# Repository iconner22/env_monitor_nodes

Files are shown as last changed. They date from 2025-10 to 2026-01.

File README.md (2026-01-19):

## Project Overview
This project implements **multihop, ad-hoc wireless sensor network (WSN)** for environmental monitoring. The system is built around Arduino UNO nodes that communicate using a 915 MHz transciever and a centeral gateway that handles requests and data storage. The gateway node requests temperature and humidity at sent intervals and collects sound data based on a monitored threshold. The network performs a discovery upon initialization which allows for ad-hoc distribution and supports multi-hop communication based on a path supplied by the gateway.

## Hardware
The system is built off of Arduino UNOs and custom PCB shields which integrate the RF transciever and sensors into the microcontroller.

<figure>
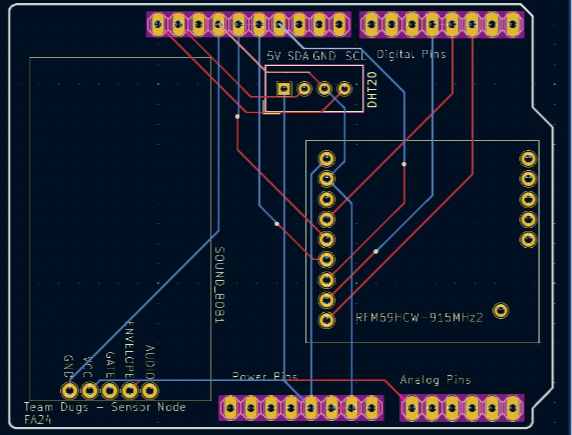
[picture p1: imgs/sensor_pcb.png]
Custom PCB for Sensor Nodes
  
  <figcaption>Custom PCB for Sensor Nodes.</figcaption>
</figure>

<figure>
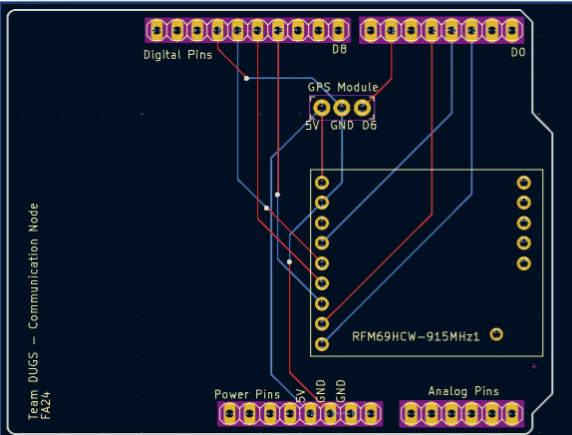
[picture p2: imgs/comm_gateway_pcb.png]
Custom PCB for Communication and Gateway Nodes
  
  <figcaption>Custom PCB for Communication and Gateway Nodes.</figcaption>
</figure>

## Node Types

The network is composed of three distinct node roles: **sensor nodes**, **communication nodes**, and a **gateway node**. All nodes share a common hardware and software base, with behavior determined by role-specific logic and sensors.

### Sensor Nodes
<figure>
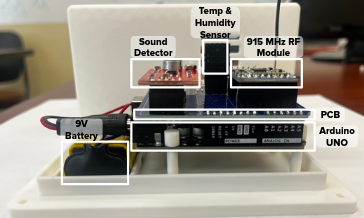
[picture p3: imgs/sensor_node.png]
Sensor Node
  
  <figcaption>Assembled Sensor Node.</figcaption>
</figure>
Sensor nodes are responsible for collecting and reporting environmental data. These nodes interface with temperature, humidity, and sound sensors.

Sensor nodes:
- Respond to gateway-initiated requests for environmental or GPS data
- Participate in network discovery and routing
- Transmit sound data upon trigger
- Prioritize low-power operation during idle periods

### Communication Nodes
<figure>
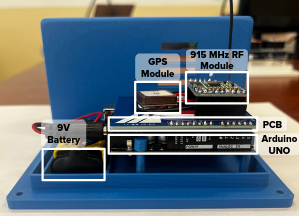
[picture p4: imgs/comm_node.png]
Communication Node
  
  <figcaption>Assembled Communication Node.</figcaption>
</figure>
Communication nodes help in the routing and localization of the network.

Communication nodes:
- Participate fully in discovery and routing
- Forward packets between sensor nodes and the gateway
- Maintain routing state during the discovery phase
- Improve network robustness and multihop coverage
- Record GPS coordinates used in trilateration

### Gateway Node
<figure>
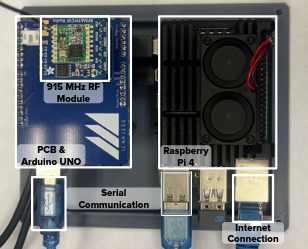
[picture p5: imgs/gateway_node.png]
Gateway Node
  
  <figcaption>Assembled Gateway Node.</figcaption>
</figure>
The gateway node serves as the **root of the network** and the primary interface between the WSN and external systems. The Arduino UNO is connected to a RasperryPi which handles the routing protocols and publishing of data.

The gateway:
- Initiates network discovery and route construction
- Requests environmental and GPS data from sensor nodes
- Receives asynchronous event-driven messages
- Aggregates data for storage in an external database
- Acts as the final destination for routed transmissions

## Network Architecture

The network operates as a **fully ad-hoc, multihop mesh**. Nodes do not rely on preconfigured routing tables; instead, routes are dynamically discovered during a **network setup (discovery) phase**.

The network supports both:
- **Request–response communication** initiated by the gateway (e.g., environmental or GPS data)
- **Asynchronous event-driven messages**, such as sound-triggered alerts that propagate back toward the gateway

## Discovery and Routing Algorithm
During the discovery process, the gateway node performs **Dijkstra’s algorithm** using the RSSI as the edge cost, a 32-bit integer is used to represent each node in the network where a 1 signals that it needs to be explored and a 0 signals that it already has been explored. This allows for a compact representation of 32 nodes, and the use of bitwise operations during the discovery process. The gateway node then stores a routing table, and upon request transmits the necessary path to the destination node. For the event based transmissions, each of the nodes stores the best path back to the gateway and transmits over this. The transmissions are handled using a baseline struct which is able to store the required data for each transmission type. The transmission is signified using an enum that specifies the type of tranmission and if it is a request or response. 

## Transmission Structure

```cpp
enum TransmissionType {
  DISCOVERY_REQUEST,
  GPS_REQUEST,
  ENV_SENSOR_REQUEST,
  DISCOVERY_RESPONSE,
  SOUND_RESPONSE,
  GPS_RESPONSE,
  ENV_SENSOR_RESPONSE,
  DISCOVERY_RESPONSE_FINISHED,
  WEIGHT_CALCS
};

/********* Transmission Struct ********/
struct TransmissionData{
    int dest;
    int curr_num_hops;
    int path[MAX_HOPS+1];
    float dataOne; // temp, latitude, RSSI
    float dataTwo; // humidity, longitude, timing
    TransmissionType dataType;
    uint32_t nodeClosedOpenEncoding; // 1 = node unvisited, 0 = visited
};
````

## Included in this repository
This repository includes the PCB design and all of the Arduino code required for the sensor, communication, and gateway nodes. Additional code is needed for the RaspberryPi to communicate with the gateway arduino. This is what handled the discovery process.

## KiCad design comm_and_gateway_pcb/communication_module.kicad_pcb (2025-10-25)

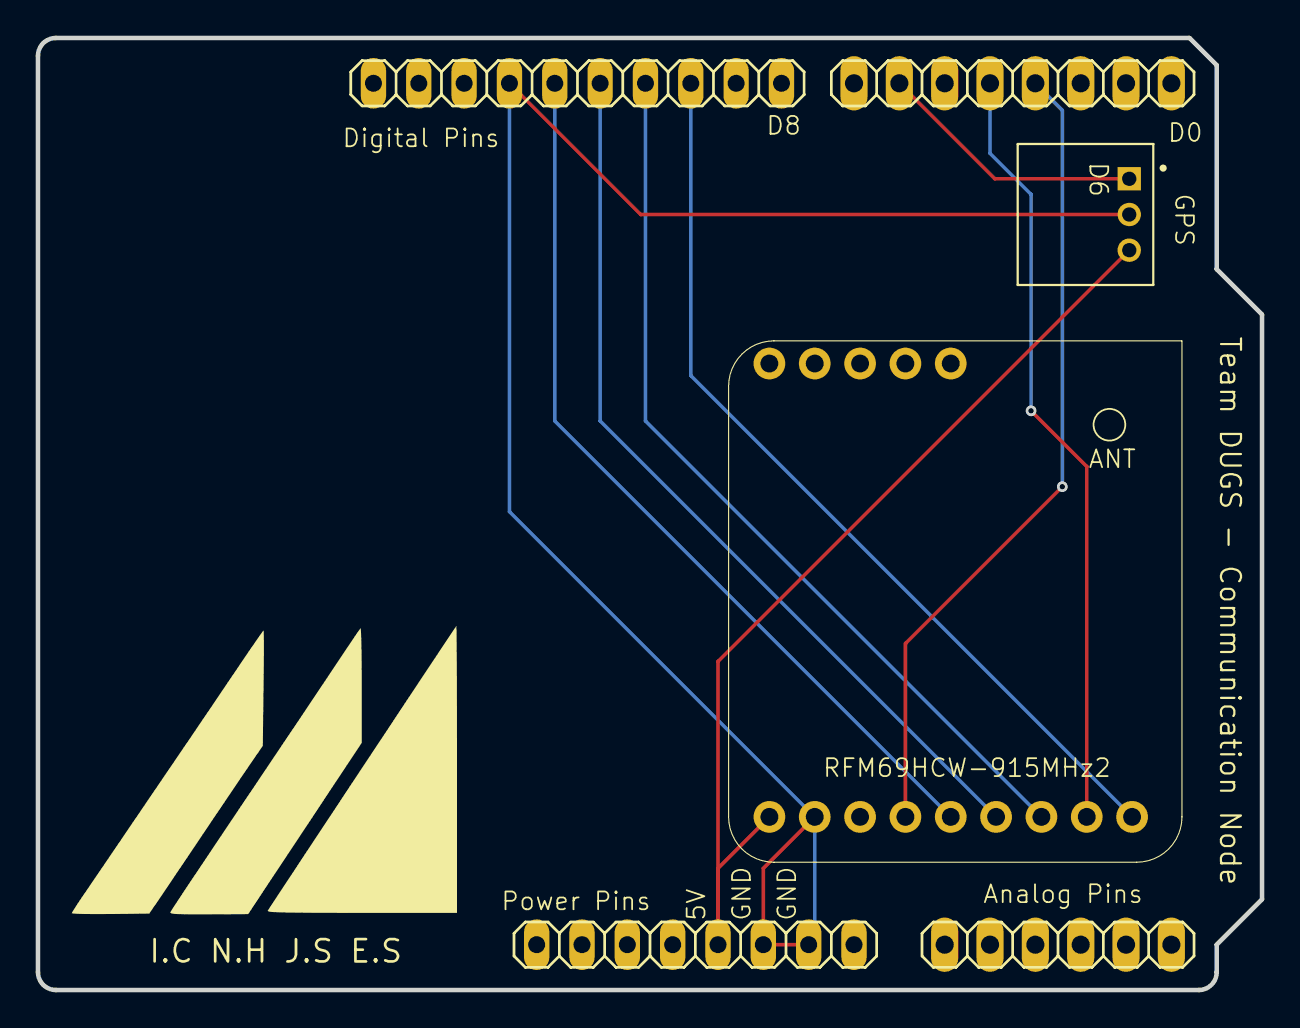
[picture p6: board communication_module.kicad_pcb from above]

Board: 2 copper layers, 68.6 x 53.3 mm, 6 parts (0 on the bottom side), 9 nets.

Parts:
ANALOG-1: PINHD-1X6; ANALOG_PINS
DIGITAL-H2: Digital_Top; DIGITAL_TOP_PINS
DIGITAL-L2: Digital_Bottom; DIGITAL_BOTTOM
J2: 61300311121; JST_S3B-PH-K-S_LF__SN_
POWER1: PINHD-1X8TH; POWER_PINS
RFM69HCW-915MHz2: RF69_MODULE

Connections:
/5V: J2.3, POWER1.5, RFM69HCW-915MHz2.1 (Vin)
/D3: DIGITAL-L2.5, RFM69HCW-915MHz2.4 (G0)
/D4: DIGITAL-L2.4, RFM69HCW-915MHz2.8 (CS)
/D6: DIGITAL-L2.2, J2.1
/D10: DIGITAL-H2.3, RFM69HCW-915MHz2.9 (RST)
/D11: DIGITAL-H2.4, RFM69HCW-915MHz2.7 (MOSI)
/D12: DIGITAL-H2.5, RFM69HCW-915MHz2.6 (MISO)
/D13: DIGITAL-H2.6, RFM69HCW-915MHz2.5 (SCK)
/GND: DIGITAL-H2.7, J2.2, POWER1.6, POWER1.7, RFM69HCW-915MHz2.2 (GND)

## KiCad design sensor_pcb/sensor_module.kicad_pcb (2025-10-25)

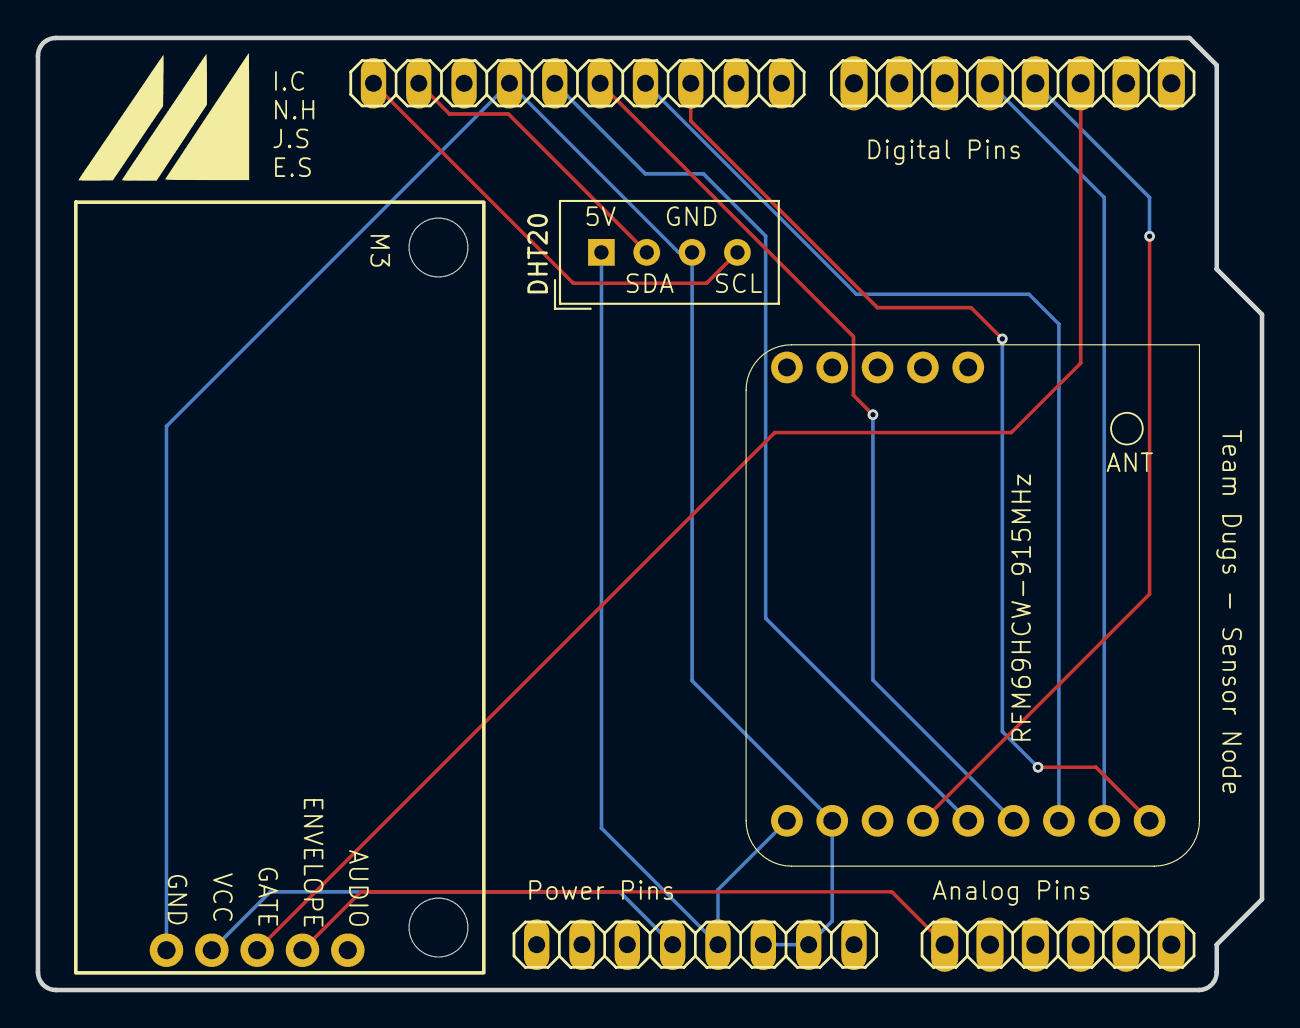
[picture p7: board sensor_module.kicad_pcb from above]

Board: 2 copper layers, 68.6 x 53.3 mm, 7 parts (0 on the bottom side), 13 nets.

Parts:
ANALOG-1: Analong Pins; ANALOG_PINS
DHT20: DHT20; DHT20-Temp-Humidity
DIGITAL-H1: Digital_Top; DIGITAL_TOP_PINS
DIGITAL-L1: Digital_Bottom; DIGITAL_BOTTOM
POWER1: Power_Pins; POWER_PINS
RFM69HCW-915MHz: RF69_MODULE
SOUND_BOB1: SOUND-BOB

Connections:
/3.3V: POWER1.4, SOUND_BOB1.2 (VCC)
/5V: DHT20.1 (VDD), POWER1.5, RFM69HCW-915MHz.1 (Vin)
/A0: ANALOG-1.1, SOUND_BOB1.4 (ENVELOPE)
/D2: DIGITAL-L1.6, SOUND_BOB1.3 (GATE)
/D3: DIGITAL-L1.5, RFM69HCW-915MHz.4 (G0)
/D4: DIGITAL-L1.4, RFM69HCW-915MHz.8 (CS)
/D10: DIGITAL-H1.3, RFM69HCW-915MHz.9 (RST)
/D11: DIGITAL-H1.4, RFM69HCW-915MHz.7 (MOSI)
/D12: DIGITAL-H1.5, RFM69HCW-915MHz.6 (MISO)
/D13: DIGITAL-H1.6, RFM69HCW-915MHz.5 (SCK)
/GND: DHT20.3 (GND), DIGITAL-H1.7, POWER1.6, POWER1.7, RFM69HCW-915MHz.2 (GND), SOUND_BOB1.1 (GND)
/SCL: DHT20.4 (SCL), DIGITAL-H1.10
/SDA: DHT20.2 (SDA), DIGITAL-H1.9

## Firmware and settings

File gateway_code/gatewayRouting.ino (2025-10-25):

// rf69 demo tx rx.pde
// -*- mode: C++ -*-
// Example sketch showing how to create a simple addressed, reliable
// messaging client with the RH_RF69 class.
// It is designed to work with the other example RadioHead69_AddrDemo_TX.
// Demonstrates the use of AES encryption, setting the frequency and
// modem configuration.
#include <SPI.h>
#include <RH_RF69.h>
#include <RHReliableDatagram.h>  
/************ Radio Setup ***************/
#define RF69_FREQ 915.0
#define MY_ADDRESS   0
//ARDUINO PINS
#define RFM69_CS    4  //
#define RFM69_INT   3  //
#define RFM69_RST   10
#define LED        13
/********** Routing Constants ********/
#define MAX_HOPS 4
#define TYPE_STR_LEN 8
#define ENCODING_BITS 32
#define BUFFERSIZE 100

// Create the radio driver and manager
RH_RF69 rf69(RFM69_CS, RFM69_INT);
RHReliableDatagram rf69_manager(rf69, MY_ADDRESS);

/******* Transmission Type Enum *********/
enum TransmissionType {
  DISCOVERY_REQUEST,
  GPS_REQUEST,
  ENV_SENSOR_REQUEST,
  DISCOVERY_RESPONSE,
  SOUND_RESPONSE,
  GPS_RESPONSE,
  ENV_SENSOR_RESPONSE,
  DISCOVERY_RESPONSE_FINISHED,
  WEIGHT_CALCS
};

/********* Transmission Struct ********/
struct TransmissionData{
    int dest;
    int curr_num_hops;
    int path[MAX_HOPS+1];
    float dataOne; //temp, latitude, rssi
    float dataTwo; //humidity, longitude, timing
    TransmissionType dataType; //consider using enums here
    uint32_t nodeClosedOpenEncoding; //1 means the node needs to be visited, 0 means it has already been visited
};


TransmissionData sentData; //instance to pass along with new data
TransmissionData recievedData; //instance to use when handling new data
//handle recieved buffer - load into buffer the size of struct
uint8_t buf[sizeof(TransmissionData)]; //ensure that this should be here
uint8_t len = sizeof(buf); //ensure that this should be here
uint16_t timeout = 2000;
uint8_t from;

// variables used for timing calculations
unsigned long startTime; //used to calculate timing for discovery
unsigned long endTime;
unsigned long elapsed_time_us; //unsigned means that it is okay if roll over happens

uint16_t clock_ticks = 0; //pulled from the timer

//estimated using micros()
unsigned long estimated_ticks;
unsigned long overflow_ticks;
unsigned long total_ticks;
float calculated_time;


void clearRecievedData(){
  recievedData.dest = -1;
  recievedData.curr_num_hops = 0;
  for (int index = 0; index <= MAX_HOPS; index++){
    recievedData.path[index] = -1;
  }
  recievedData.dataOne = -1.0;
  recievedData.dataTwo = -1.0;
  recievedData.dataType = DISCOVERY_REQUEST;
  recievedData.nodeClosedOpenEncoding = 0;
}


void setupTimer(){
  // Set Timer1 to overflow at the desired rate
TCCR1A = 0;                  // Normal operation mode
TCCR1B = 0;                  // Stop the timer initially
TCCR1B |= (1 << CS10);       // No prescaler (16 MHz system clock)

}

void clearSentData(){
  sentData.dest = -1;
  sentData.curr_num_hops = 0;
  for (int index = 0; index <= MAX_HOPS; index++){
    sentData.path[index] = -1;
  }
  sentData.dataOne = -1.0;
  sentData.dataTwo = -1.0;
  sentData.dataType = DISCOVERY_REQUEST;
  sentData.nodeClosedOpenEncoding = 0;
}

void nodeExplore(uint32_t& nodeEncoding){

    for (int index = 0; index < ENCODING_BITS; index++){
      if (nodeEncoding & (1 << index)){
        clearRecievedData(); //reset the data 
        recievedData.path[1] = MY_ADDRESS; //hardcoded so that it is is reversed the same way that the other nodes are
        recievedData.dataType = DISCOVERY_RESPONSE;
        Serial.print("Trying to explore node: ");Serial.println(index);
        sentData.dataType = DISCOVERY_REQUEST;
        if(rf69_manager.sendtoWait((uint8_t *)&sentData, sizeof(sentData) ,index)){
          recievedData.curr_num_hops++;
          recievedData.path[0] = index; //hardcoded so that it is is reversed the same way that the other nodes are
          int time_counter = 0;
          int rssi_counter = 0;
          sentData.dataType = WEIGHT_CALCS;

          float maxTimingVal = -INFINITY;
          float minTimingVal = INFINITY;
          float maxRSSIVal = -INFINITY;
          float minRSSIVal = INFINITY;

          for (int i = 0; i<5; i++){
            TCCR1B = 0;                  // Stop the timer
            TCNT1 = 0;                   // Reset the counter
            TIFR1 |= (1 << TOV1);        // Clear the overflow bit 
            TCCR1B |= (1 << CS10);       // Start the timer
            startTime = micros();       //start micros (might need to find a way for micros overflow)
            if(rf69_manager.sendtoWait((uint8_t *)&sentData, sizeof(sentData) ,index)){
              TCCR1B &= ~((1 << CS11) | (1 << CS10));   //stop the timer
              endTime = micros();
              clock_ticks = TCNT1;
              elapsed_time_us = endTime - startTime;
              estimated_ticks = elapsed_time_us * 16UL; //16 of the 62.5ns per 1 us
              overflow_ticks = (estimated_ticks/65536UL) * 65536UL; //finds the total number of overflow times (int) then multiplies it by the number of ticks
              total_ticks = overflow_ticks + clock_ticks;
              calculated_time = total_ticks * 0.0625;
              if (calculated_time > elapsed_time_us + 2048){
                calculated_time -= 4096; //avoids a case where micros rolled over right before the counter did
              }
              recievedData.dataTwo += (calculated_time)/2; //oneway transmission
              time_counter++;
              recievedData.dataOne += rf69.lastRssi();
              rssi_counter++;

              if ((calculated_time/2) > maxTimingVal){
                maxTimingVal = calculated_time/2;
              }
              if ((calculated_time/2) < minTimingVal){
                minTimingVal = calculated_time/2;
              }

              if (rf69.lastRssi() > maxRSSIVal){
                maxRSSIVal = rf69.lastRssi();
              }
              if (rf69.lastRssi() < minRSSIVal){
                minRSSIVal = rf69.lastRssi();
              }
        }
        delay(10);
      }

      recievedData.dataOne-=minRSSIVal;
      recievedData.dataOne-=maxRSSIVal;

      recievedData.dataTwo -=minTimingVal;
      recievedData.dataTwo -= maxTimingVal;

      recievedData.dataOne/=rssi_counter - 2; //subtract two because of dropping the max and min values
      recievedData.dataTwo/=time_counter -2;
      printDataJson();
    }
  }
  }
  clearRecievedData();
  recievedData.dataType = DISCOVERY_RESPONSE_FINISHED;
  printDataJson();
}
void printDataJson(){
  //rpi calculates the timing offset
  switch (recievedData.dataType){
    case DISCOVERY_RESPONSE_FINISHED:
      Serial.print(F("{ \"Type\": \"DISCOVERY REQUEST FINISHED\" "));
      Serial.println(F("}"));
      break;
    case DISCOVERY_RESPONSE: //add reverse path to the explore for gateway to get a standard order of the discovered in path[0] TODO - Ian!!!
      Serial.print(F("{ \"Type\": \"DISCOVERY\", "));
      Serial.print(F("\"Edge\": ("));Serial.print(recievedData.path[0]);Serial.print(F(","));Serial.print(recievedData.path[1]);Serial.print(F("), "));
      Serial.print(F("\"RSSI\": "));Serial.print(recievedData.dataOne,6);Serial.print(F(","));
      Serial.print(F("\"Time\": "));Serial.print(recievedData.dataTwo,6);Serial.print(F(","));
      Serial.print(F("\"Total Hops\": "));Serial.print(recievedData.curr_num_hops);Serial.print(F(","));

      Serial.print(F("\"Path\": \"["));
      for (int index = 0; index <= recievedData.curr_num_hops; index++){
        Serial.print(recievedData.path[index]);
        if (index != recievedData.curr_num_hops){
          Serial.print(F(","));
        }
      }
      Serial.print(F("]\""));

      Serial.println(F("}"));
      break;
    case GPS_RESPONSE:
      Serial.print(F("{ \"Type\": \"GPS\", "));
      Serial.print(F("\"Address\": "));Serial.print(recievedData.path[0]);Serial.print(F(","));
      Serial.print(F("\"Latitude\": "));Serial.print(recievedData.dataOne,6);Serial.print(F(","));
      Serial.print(F("\"Longitude\": "));Serial.print(recievedData.dataTwo,6);
      Serial.println(F("}"));
      break;
    case ENV_SENSOR_RESPONSE:
      Serial.print(F("{ \"Type\": \"ENV\", "));
      Serial.print(F("\"Address\": "));Serial.print(recievedData.path[0]);Serial.print(F(","));
      Serial.print(F("\"Temperature\": "));Serial.print(recievedData.dataOne,6);Serial.print(F(","));
      Serial.print(F("\"Humidity\": "));Serial.print(recievedData.dataTwo,6);
      Serial.println(F("}"));
      break;

    case SOUND_RESPONSE:
      Serial.print(F("{ \"Type\": \"SOUND\", "));
      Serial.print(F("\"Address\": "));Serial.print(recievedData.path[0]);Serial.print(F(","));
      Serial.print(F("\"Sound Level\": "));Serial.print(recievedData.dataOne);Serial.print(F(","));
      Serial.print(F("\"Path\": \"["));
      for (int index = 0; index <= recievedData.curr_num_hops; index++){
        Serial.print(recievedData.path[index]);
        if (index != recievedData.curr_num_hops){
          Serial.print(F(","));
        }
      }
      Serial.print(F("]\""));
      Serial.println(F("}"));
      break;
    default:
      break;      
    }

}
//**************Globals Used for Reading In Serial *****************//
bool response_recieved = true;
int transmission_type;
int dest,p0,p1,p2,p3,p4,num_hops;
uint32_t node_encoding;
char inputBuffer[100];
int bytesRead;



//setup function
void setup() {
  Serial.begin(9600);

  pinMode(RFM69_RST, OUTPUT);
  digitalWrite(RFM69_RST, LOW);
  // manual reset
  digitalWrite(RFM69_RST, HIGH);
  delay(10);
  digitalWrite(RFM69_RST, LOW);
  delay(10);

  if (!rf69_manager.init()) {
    Serial.println("RFM69 radio init failed");
    while (1);
  }
  Serial.println("RFM69 radio init OK!");

  if (!rf69.setFrequency(RF69_FREQ)) {
    Serial.println("setFrequency failed");
  }

  rf69.setTxPower(20, true);  // range from 14-20 for power, 2nd arg must be true for 69HCW

  // The encryption key has to be the same as the one in the client
  uint8_t key[] = { 0x01, 0x02, 0x03, 0x04, 0x05, 0x06, 0x07, 0x08,
                    0x01, 0x02, 0x03, 0x04, 0x05, 0x06, 0x07, 0x08 };
  rf69.setEncryptionKey(key);
  Serial.print(F("RFM69 radio @"));  Serial.print((int)RF69_FREQ);  Serial.println(F(" MHz"));
  
  setupTimer();
}


void loop() {
  //expect this format: dest transmission_type path0 path1 path2 path3 path4 num_hops (put -1 in the case of no path)
    if (Serial.available()){
    Serial.println(" 'Test': ");
    bytesRead = Serial.readBytesUntil('\n', inputBuffer, BUFFERSIZE-1);
    inputBuffer[bytesRead] = '\0';
    if (sscanf(inputBuffer, "%d %d", &dest, &transmission_type) != 2){
      Serial.println(F("Issue Parsing Data"));
    }
    switch (transmission_type){
      case (0):
        Serial.println("Reading In Discovery Data");
        if (sscanf(inputBuffer, "%d %d %d %d %d %d %d %u", &dest, &transmission_type, &p0, &p1, &p2, &p3, &p4, &node_encoding) != 8){
          Serial.println(F("Issue parsing data"));
        }
        break;
      default:
        Serial.println("Reading In Typical Data");
        if (sscanf(inputBuffer, "%d %d %d %d %d %d %d %d", &dest, &transmission_type, &p0, &p1, &p2, &p3, &p4, &num_hops) != 8){
          Serial.println(F("Issue Parsing Data"));
        }
        break;
    }
    sentData.dest = dest;
    switch (transmission_type){
      case(0)://discovery request
      if (dest == MY_ADDRESS){ //explore this node if it is the destination
        nodeExplore(node_encoding);

      }
      else{ //send message along the path
        sentData.dataType = DISCOVERY_REQUEST;
        sentData.path[0] = MY_ADDRESS;
        sentData.path[1] = p1;
        sentData.path[2] = p2;
        sentData.path[3] = p3;
        sentData.path[4] = p4;
        sentData.curr_num_hops = 0;
        sentData.nodeClosedOpenEncoding = node_encoding;

        rf69_manager.sendtoWait((uint8_t *)&sentData, sizeof(sentData) ,sentData.path[1]);
      }
      break; 
      
      case (1): //gps request
        sentData.dataType = GPS_REQUEST;
        sentData.path[0] = MY_ADDRESS;
        sentData.path[1] = p1;
        sentData.path[2] = p2;
        sentData.path[3] = p3;
        sentData.path[4] = p4;
        sentData.curr_num_hops = 0;

        rf69_manager.sendtoWait((uint8_t *)&sentData, sizeof(sentData) ,sentData.path[1]);
        break;

      case (2): //env request
        sentData.dataType = ENV_SENSOR_REQUEST;
        sentData.path[0] = p0;
        sentData.path[1] = p1;
        sentData.path[2] = p2;
        sentData.path[3] = p3;
        sentData.path[4] = p4;
        sentData.curr_num_hops = 0;
        rf69_manager.sendtoWait((uint8_t *)&sentData, sizeof(sentData) ,sentData.path[1]);

      break;
      default:
        Serial.println(F("Issue with datatype, please enter a valid request"));
        break;
    }
  }
  // Check the envelope input
  if (rf69_manager.available()) {
    // Wait for a message addressed to us from the client
    len = sizeof(buf);
    if (rf69_manager.recvfromAckTimeout(buf, &len, timeout, &from)) {
      buf[len] = 0; // zero out remaining string
      memcpy(&recievedData, buf, len );
      Serial.println(recievedData.dest);
      if (recievedData.dest == MY_ADDRESS){
        //check what the data request is and process it appropriately
        switch (recievedData.dataType){
          case DISCOVERY_RESPONSE:
            recievedData.curr_num_hops ++;
            printDataJson();
            break;
          case GPS_RESPONSE:
            recievedData.curr_num_hops ++;
            printDataJson();
            break;
          case ENV_SENSOR_RESPONSE:
            recievedData.curr_num_hops ++;
            printDataJson();
            break;
          case SOUND_RESPONSE:
            recievedData.curr_num_hops ++;
            printDataJson();
            break;
          case DISCOVERY_RESPONSE_FINISHED:
            recievedData.curr_num_hops ++;
            printDataJson();
            break;
          default:
            Serial.println(F("Invalid Message Type for GATEWAY node"));
            break;
            }
      }
      else{
        return; //should only be interacting if it it is for the GATEWAY
      }
    } 
  }


}

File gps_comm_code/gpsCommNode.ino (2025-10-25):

// rf69 demo tx rx.pde
// -*- mode: C++ -*-
// Example sketch showing how to create a simple addressed, reliable
// messaging client with the RH_RF69 class.
// It is designed to work with the other example RadioHead69_AddrDemo_TX.
// Demonstrates the use of AES encryption, setting the frequency and
// modem configuration.
#include <SPI.h>
#include <RH_RF69.h>
#include <RHReliableDatagram.h>
#include <SoftwareSerial.h>  // make sure this is NewSoftSerial beta 11 - now called SoftwareSerial
#include <TinyGPS++.h>       
#include "LowPower.h"

/************ Radio Setup ***************/
#define RF69_FREQ 915.0
#define MY_ADDRESS   1
#define GATEWAY_ADDRESS 0 //check that this is a valid address
#define ENCODING_BITS 32

//ARDUINO PINS
#define RFM69_CS    4  //
#define RFM69_INT   3  //
#define RFM69_RST   10
/********** Routing Constants ********/
#define MAX_HOPS 4
#define TYPE_STR_LEN 8

// Create the radio driver and manager
RH_RF69 rf69(RFM69_CS, RFM69_INT);
RHReliableDatagram rf69_manager(rf69, MY_ADDRESS);
/************ GPS Setup ***************/
SoftwareSerial* GPSSerial = nullptr;
TinyGPSPlus gps;                     // instantiate the tinygps instance and call it 'gps'
volatile unsigned long timeEnteringGPS;
volatile unsigned long currTime;


/******* Transmission Type Enum *********/
enum TransmissionType {
  DISCOVERY_REQUEST,
  GPS_REQUEST,
  ENV_SENSOR_REQUEST,
  DISCOVERY_RESPONSE,
  SOUND_RESPONSE,
  GPS_RESPONSE,
  ENV_SENSOR_RESPONSE,
  DISCOVERY_RESPONSE_FINISHED,
  WEIGHT_CALCS

};

/********* Transmission Struct ********/
struct TransmissionData{
    int dest;
    int curr_num_hops;
    int path[MAX_HOPS+1];
    float dataOne; //temp, latitude, rssi
    float dataTwo; //humidity, longitude, timing
    TransmissionType dataType; //consider using enums here
    uint32_t nodeClosedOpenEncoding; //1 means the node needs to be visited, 0 means it has already been visited
};


TransmissionData sentData; //instance to pass along with new data
TransmissionData recievedData; //instance to use when handling new data


//handle recieved buffer - load into buffer the size of struct
uint8_t buf[sizeof(TransmissionData)]; //ensure that this should be here
uint8_t len = sizeof(buf); //ensure that this should be here
uint16_t timeout = 2000;
uint8_t from;
unsigned long startTime; //used to calculate timing for discovery

int tmpPath[MAX_HOPS+1];
//nbr struct: hops, rssi, addr
// determine best nbr by the sum of rssi
struct NeighborData{ // could get rid of path
  int address;
  int numberHops;
  float totalRSSI;
  int path[MAX_HOPS+1];
};

int current_neighbors = 0;
int best_path_index = 0;
const int max_neighbors = 10;
NeighborData neighborList[max_neighbors];

void clearRecievedData(){
  recievedData.dest = -1;
  recievedData.curr_num_hops = 0;
  for (int index = 0; index <= MAX_HOPS; index++){
    recievedData.path[index] = -1;
  }
  recievedData.dataOne = -1.0;
  recievedData.dataTwo = -1.0;
  recievedData.dataType = DISCOVERY_REQUEST;
  recievedData.nodeClosedOpenEncoding = 0;
}

void clearSentData(){
  sentData.dest = -1;
  sentData.curr_num_hops = 0;
  for (int index = 0; index <= MAX_HOPS; index++){
    sentData.path[index] = -1;
  }
  sentData.dataOne = -1.0;
  sentData.dataTwo = -1.0;
  sentData.dataType = DISCOVERY_REQUEST;
  sentData.nodeClosedOpenEncoding = 0;
}

void reverse_path(int inputList[], int numHops){
  int counter = 0;
  for (int original_index = numHops; original_index >= 0; original_index--){
    sentData.path[counter] = inputList[original_index];
    counter++;
  }
}
//this honestly might only need to be on the sound node.
void buildNeighbor(){
//information to get back to the gateway node, path needs to get reversed before traversing back to gateway
  NeighborData newNbr;
  newNbr.address = from;
  recievedData.path[recievedData.curr_num_hops] = MY_ADDRESS;
  memcpy(newNbr.path, recievedData.path, sizeof(recievedData.path));
  newNbr.numberHops = recievedData.curr_num_hops;
  newNbr.path[newNbr.numberHops] = MY_ADDRESS;

  newNbr.totalRSSI = rf69.lastRssi();
  if (current_neighbors >= max_neighbors ){
      current_neighbors = current_neighbors%max_neighbors; //TODO - fix this bandaid
  }
  neighborList[current_neighbors] = newNbr;
  if (neighborList[best_path_index].totalRSSI > neighborList[current_neighbors].totalRSSI){
    best_path_index = current_neighbors;
  }
  current_neighbors ++; 

  //add something to delete the worst one.
}

void nodeExplore(uint32_t& nodeEncoding){
    memcpy(tmpPath, recievedData.path, sizeof(recievedData.path)); //path taken to get here
    int next_index = recievedData.curr_num_hops+1;
    for (int index = 0; index < ENCODING_BITS; index++){
      if (nodeEncoding & (1 << index)){
        clearSentData(); //reset the data 
        sentData.dataType = DISCOVERY_REQUEST;
        sentData.curr_num_hops = recievedData.curr_num_hops; //initial hops before something is added
        sentData.dest = MY_ADDRESS; //makes sure that the next exploration node follows this properly
        memcpy(sentData.path, recievedData.path, sizeof(recievedData.path)); //make sure the path is still being transmit
        if(rf69_manager.sendtoWait((uint8_t *)&sentData, sizeof(sentData) ,index)){
          tmpPath[next_index] = index; //add discovered node to the list
          int counter = 0;
          sentData.dataType =  WEIGHT_CALCS;
          for (int i = 0; i<5; i++){
            startTime = millis();
            if(rf69_manager.sendtoWait((uint8_t *)&sentData, sizeof(sentData) ,index)){
              sentData.dataTwo += (millis() - startTime)/2; //oneway transmission
              sentData.dataOne += rf69.lastRssi();
              counter++;
        }
      }
      sentData.dataOne/=counter;
      sentData.dataTwo/=counter;
      reverse_path(tmpPath, next_index);
      sentData.dataType = DISCOVERY_RESPONSE;

      sentData.dest = GATEWAY_ADDRESS;
      sentData.curr_num_hops = 1; //from the found node to current
      rf69_manager.sendtoWait((uint8_t *)&sentData, sizeof(sentData),sentData.path[sentData.curr_num_hops+1]); //send back down the path
    }
  }
  
  }

  clearSentData();
  sentData.dataType = DISCOVERY_RESPONSE_FINISHED;
  sentData.dest = GATEWAY_ADDRESS;
  reverse_path(recievedData.path, recievedData.curr_num_hops);
  rf69_manager.sendtoWait((uint8_t *)&sentData, sizeof(sentData),sentData.path[sentData.curr_num_hops+1]); //all finished flag down the path
}
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

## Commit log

2025-10-25 added into folders and removed proj specific files
    [communication_module.kicad_pcb, communication_module.kicad_sch, sensor_module.kicad_pcb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]
2025-10-25 Arduino code added
2026-01-19 Add project overview and detailed README
    This README provides an overview of the multihop, ad-hoc wireless sensor network project, detailing hardware, node types, network architecture, and transmission structure.
